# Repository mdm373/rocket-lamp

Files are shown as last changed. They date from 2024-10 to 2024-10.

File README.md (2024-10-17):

# rocket lamp

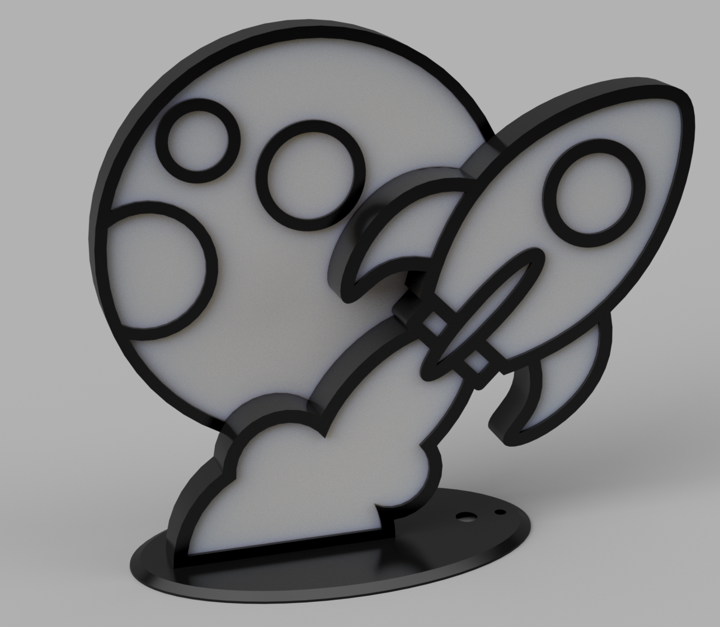
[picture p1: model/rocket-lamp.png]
render


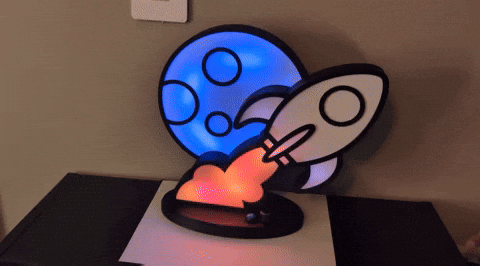
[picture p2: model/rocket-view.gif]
animated


# Assemble

## Parts

* PLA Filament (Black + White) < 250g of both required.
* Hot Glue
* Hookup wire (26 AWG)
* Raspberry Pi Pico
* WS2812B RGB LED strip (51 LEDs by default)
* Three Terminal B10K Potentiometer
  * Lamp base modeled for 7mm diameter profile 
* SPST Momentary Push Button
  * Lamp base designed for 13 mm diameter profile
* 2 - M3x8mm countersunk screws (lamp base fasteners)
* 2 - M3 heat set threaded inserts
* 4 - M2x6mm socketheaded screws (pi pico fasteners)
* AC to 5V DC Adapter
  * alternatively, power directly from USB

## Steps

* Print each [STL](/model/stl) file. Use white or translucent filament for cover files. Print 4 instances of peg files.
  * printable build area of at least 280mm required
* I would recommend wiring up / mounting the moon and rocket LED strips and enclosing them in the lamp body before before assembling the base.
  * Glue LEDs across the inner back of the container, 
  * Hot glue the white cover to the inside of the outer cover outline first
  * Hot glue Pegs to inside of container, thinly hot glue cover outline to container
  * Connect moon to rocket container, connect rocket to base top
* Follow the [wire diagram](wire/rocket-lamp_bb.png) below for wiring up the base
* Image Pi Pico with lamp hex file. Either:
  * grab latest version from project releases
  * compile from source using steps below. CMAKE file definitions enable alternate LED counts, PIN selections, etc...
  
# Compile From Source

Built on MacOS using the PICO SDK (modified from pico-examples pio/ws2812)

* [PICO SDK](https://github.com/raspberrypi/pico-sdk) Notes 
  * See: https://datasheets.raspberrypi.com/pico/getting-started-with-pico.pdf
  * For Step `9.1.1. Installing the Toolchain`, install `gcc-arm-embedded` instead of `arm-none-eabi-gcc`
* Run `sh ./configure` for initial cmake configure
* Reconnect pico as needed holding bootselector button
* Run `sh ./deploy.sh` to build and copy to pico

# Wire Diagram

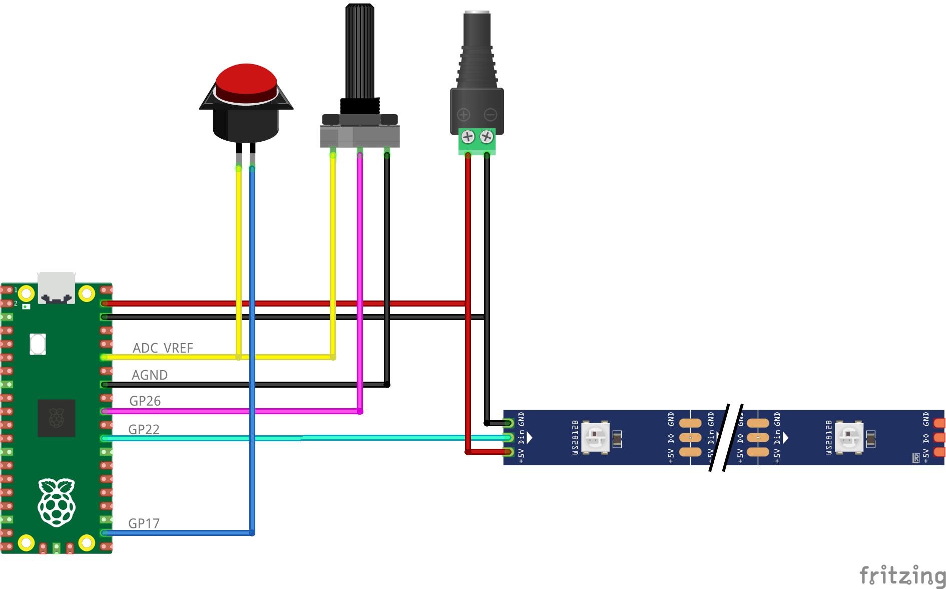
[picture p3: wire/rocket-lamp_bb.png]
bread board


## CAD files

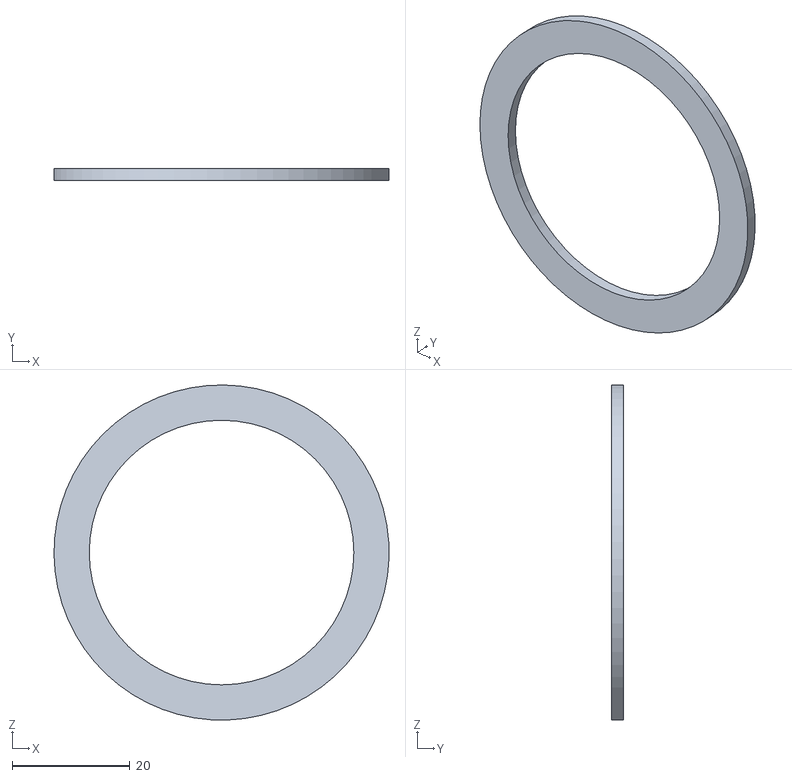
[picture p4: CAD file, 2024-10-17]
model/stl/rocket-lamp_Rocket Lamp v19_Root_1_moon_1_big-moon-crater_1_big-moon-crater.stl
57.0 x 2.00 x 57.0

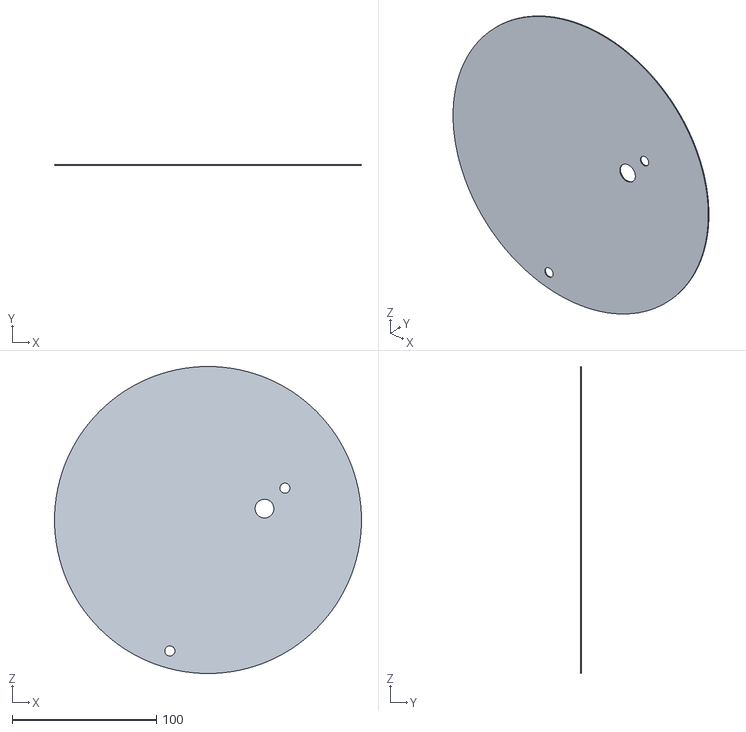
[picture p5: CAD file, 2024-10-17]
model/stl/rocket-lamp_Rocket Lamp v19_Root_1_moon_1_moon-conver_1_moon-conver.stl
212.6 x 0.75 x 212.6

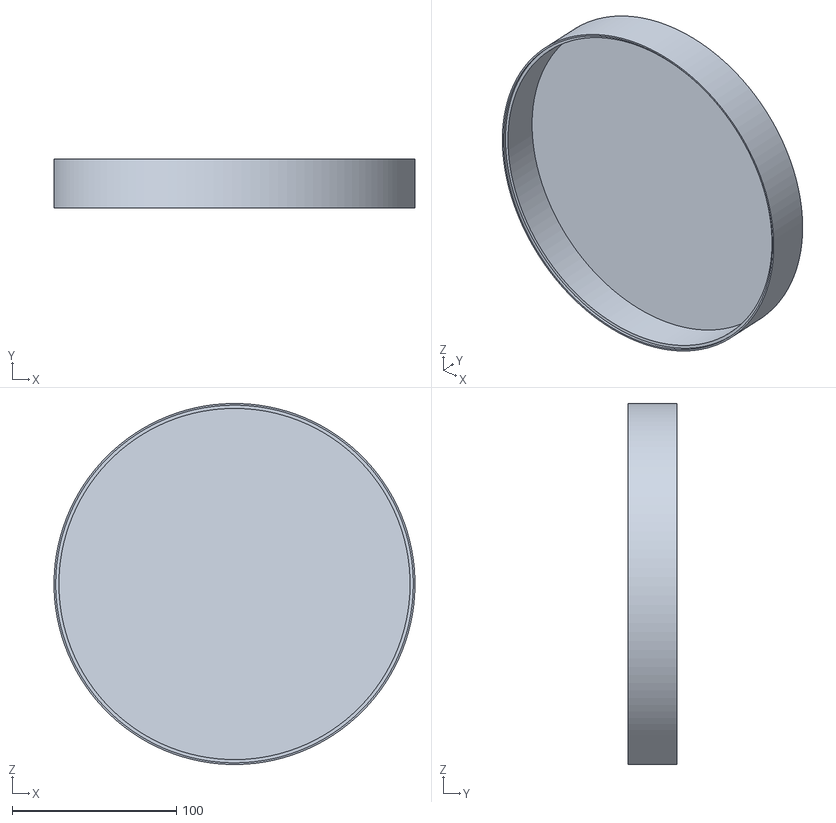
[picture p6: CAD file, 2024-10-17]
model/stl/rocket-lamp_Rocket Lamp v19_Root_1_moon_1_moon-container_1_moon-container.stl
220.0 x 30.0 x 220.0

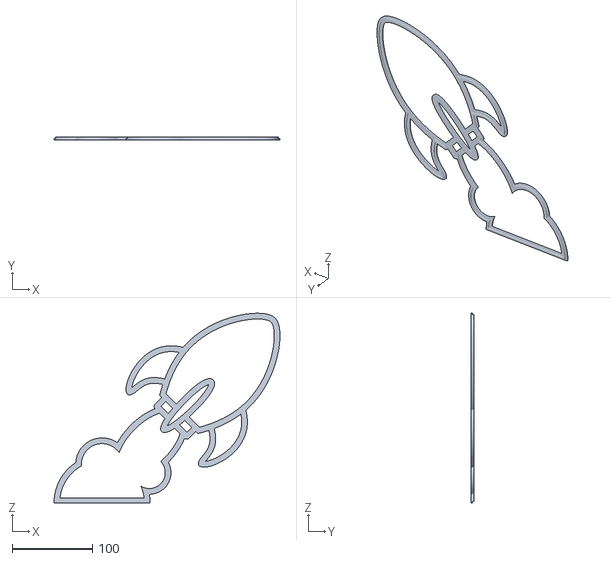
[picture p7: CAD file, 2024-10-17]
model/stl/rocket-lamp_Rocket Lamp v19_Root_1_rocket_1_rocket-lid-outer_1_rocket-lid-outer.stl
282.1 x 4.00 x 236.6

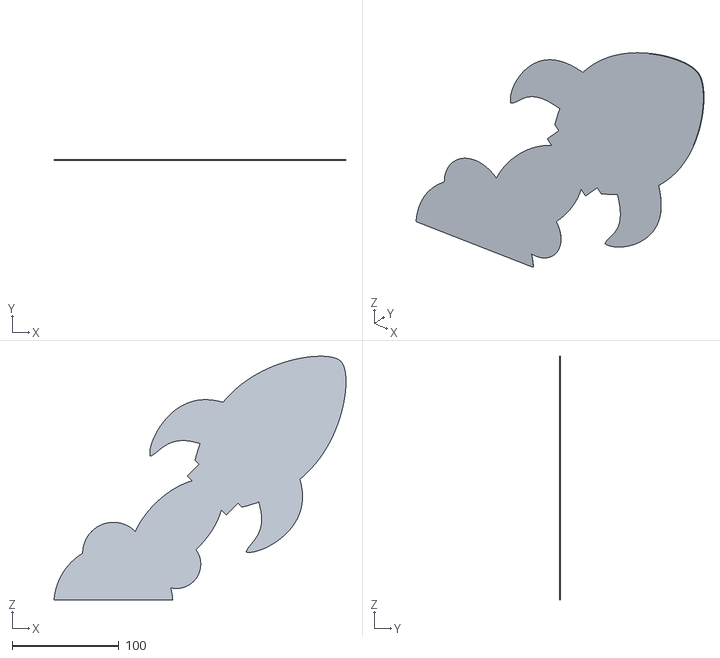
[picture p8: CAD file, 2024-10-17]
model/stl/rocket-lamp_Rocket Lamp v19_Root_1_rocket_1_rocket-cover_1_rocket-cover.stl
273.5 x 0.75 x 228.2

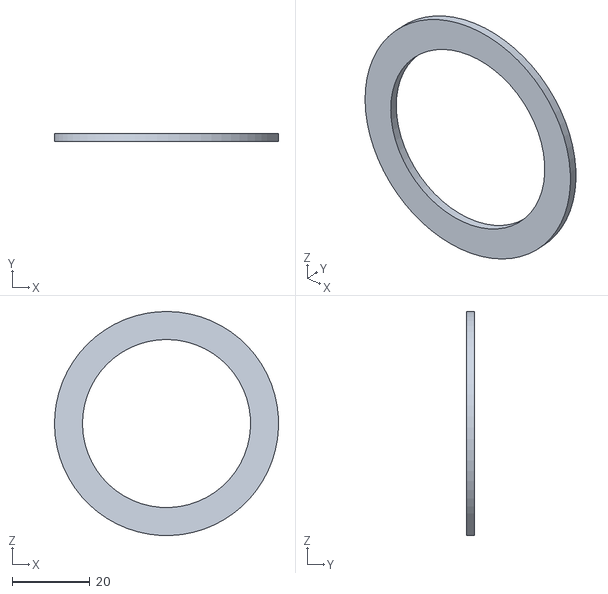
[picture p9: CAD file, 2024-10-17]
model/stl/rocket-lamp_Rocket Lamp v19_Root_1_rocket_1_lid-circle_1_lid-circle.stl
57.6 x 2.00 x 57.6

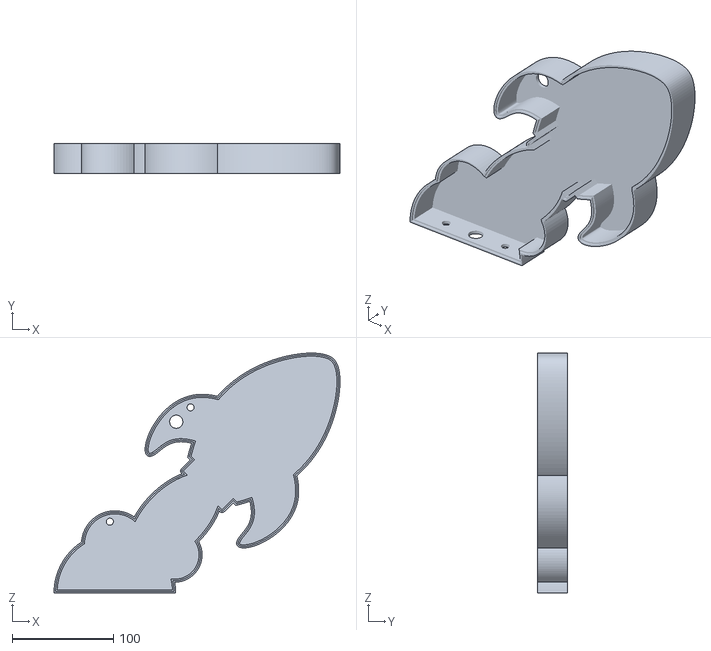
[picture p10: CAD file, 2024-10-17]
model/stl/rocket-lamp_Rocket Lamp v19_Root_1_rocket_1_rocket-container_1_rocket-container.stl
282.1 x 30.0 x 236.6

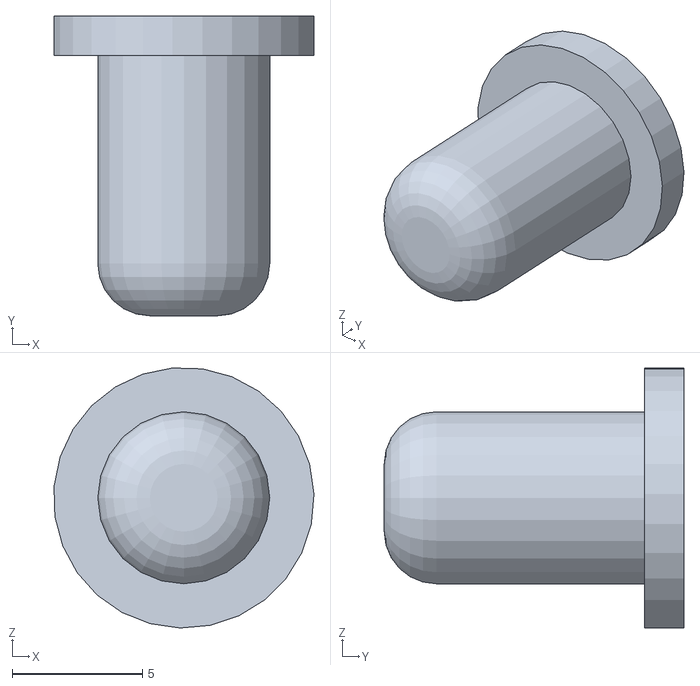
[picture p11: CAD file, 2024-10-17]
model/stl/rocket-lamp_Rocket Lamp v19_Root_1_pegs_1_peg(x4).stl
9.98 x 11.5 x 9.98

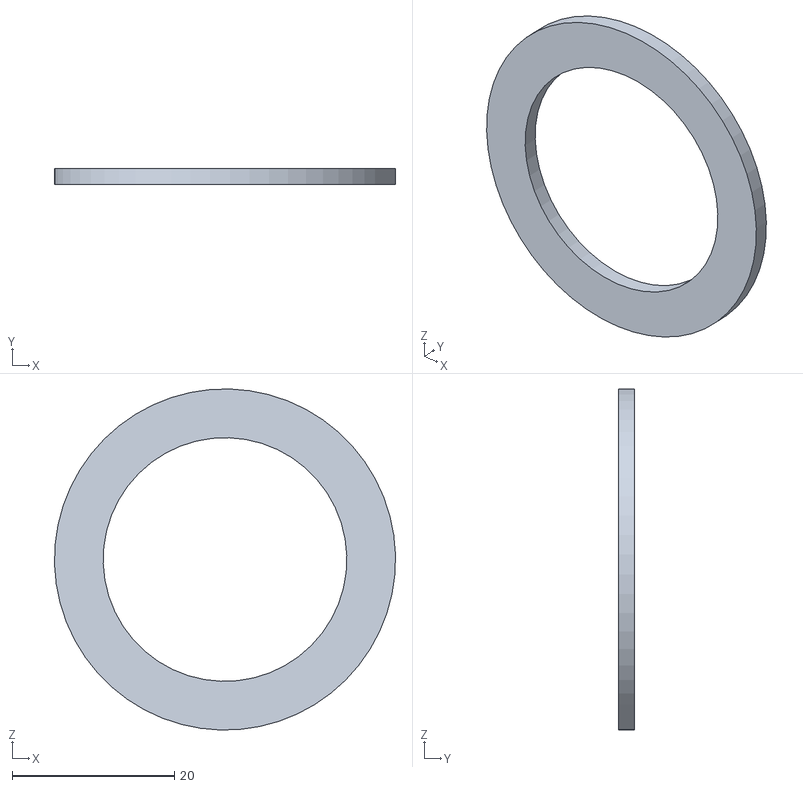
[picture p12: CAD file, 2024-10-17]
model/stl/rocket-lamp_Rocket Lamp v19_Root_1_moon_1_little-moon-crater_1_little-moon-crater.stl
42.0 x 2.00 x 42.0

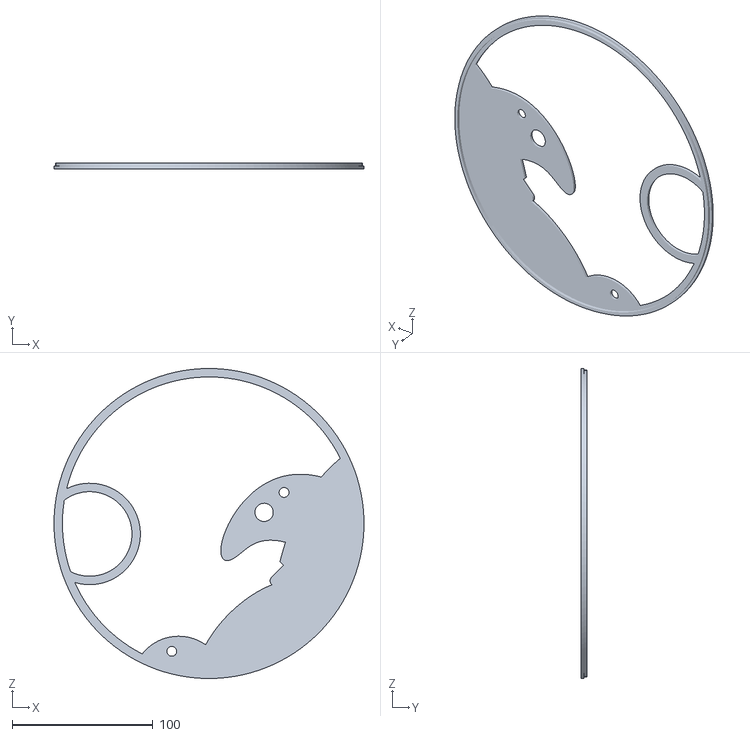
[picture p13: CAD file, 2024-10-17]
model/stl/rocket-lamp_Rocket Lamp v19_Root_1_moon_1_moon-outer_1_moon-outer.stl
220.0 x 4.00 x 220.0

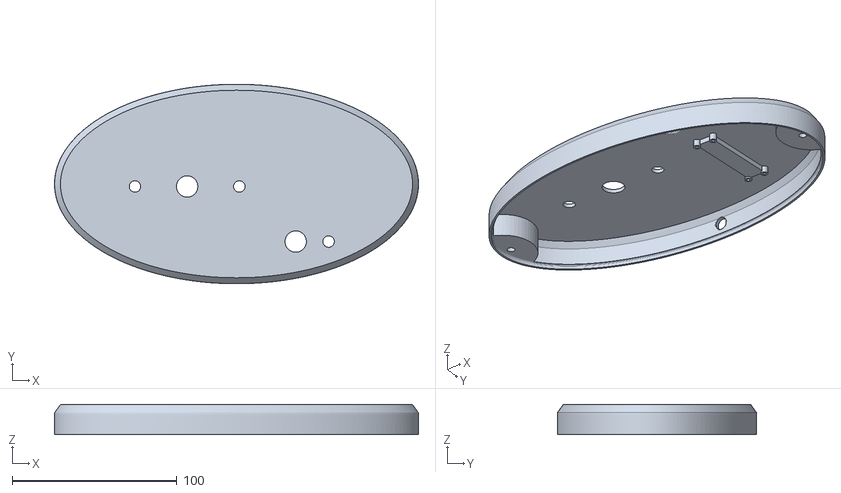
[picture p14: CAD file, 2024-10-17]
model/stl/rocket-lamp_Rocket Lamp v19_Root_1_base_1_base-top_1_base-top.stl
221.3 x 121.3 x 18.2

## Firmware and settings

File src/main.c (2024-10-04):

#include <stdlib.h>

#include "poll_button.h"
#include "read_adc.h"
#include "rgb_color.h"
#include "view.h"

int main() {
  read_adc_init(ADC_PIN);
  rgb_color_init(WS2812_PIN, IS_RGBW);
  View views[] = {&view_rainbow, &view_rocket, &view_white, &view_mix};
  uint8_t view_count = sizeof(views) / sizeof(views[0]);
  ButtonState button_state;
  uint8_t view_index = 0;
  views[view_index](BUTTON_ACTION_PRESS_LONG_DOWN, 1.0f);
  sleep_ms(FRAME_MS);
  while (1) {
    const ButtonAction button_action = poll_button(BUTTON_PIN, FRAME_MS, &button_state);
    const float scale = read_adc_percent();
    if (button_action == BUTTON_ACTION_PRESS_LONG_DOWN) {
      view_index = (view_index + 1) % view_count;
    }
    views[view_index](button_action, scale);
    sleep_ms(FRAME_MS);
  }
}
